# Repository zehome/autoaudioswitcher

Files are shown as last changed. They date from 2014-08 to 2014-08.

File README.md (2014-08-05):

autoaudioswitcher
=================

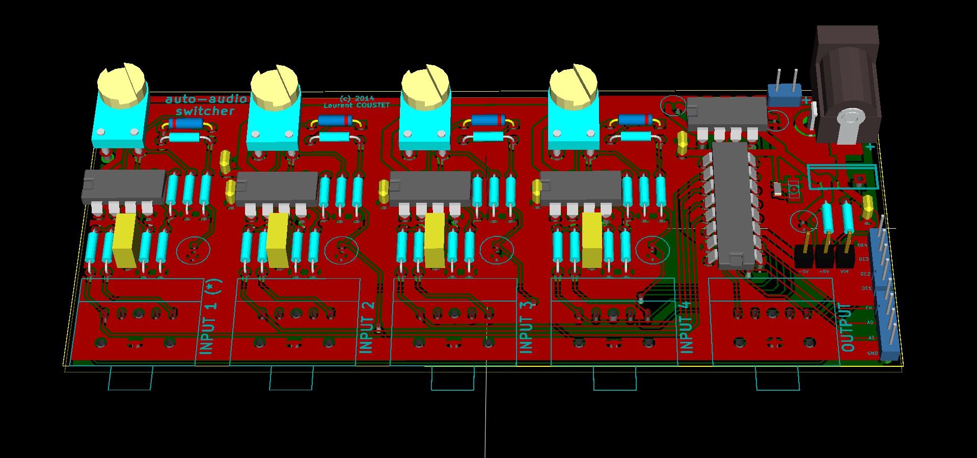
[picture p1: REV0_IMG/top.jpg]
3D_board_rev0


Introduction
------------
With vintage amplifiers, you have limited input switching capabilities. And they are all manual.
This projects aims to solve this problem.

I have an old kenwood KA-4002 (http://www.hifivintage.eu/product.php?id_product=476) which I love.

KA-4002

So, my solution to this problem, automatic audio input switcher.
Basically, the system will detect which audio input has a signal, and switch to it using a solid state MUX.

The project is in early state. Prototype circuit works on a breadbord. First test PCB done and sent to the factory.

Theory of operation
-------------------
Stereo input is muxed using 10k resistors and AC coupled into an amplifier (saturated).
Then, the signal is compared to a reference voltage using a comparator which charges a CAP.
A MCU will then poll the charge of the CAP and trigger the MUX (ADG409) to switch on the output if needed. (Programmed in the MCU)

Status
------
Early design stage.

Breadboard prototype working.

Testing PCB done and sent to the factory. Gerbers available in GERBERS_REV0/.

Tools
-----
KiCAD 20140622 + bzr4027 (r4027)

Hackaday.io entry
-----------------
http://hackaday.io/project/2282-automatic-audio-input-switcher

OSHW: Automatic audio input switcher based on audio activity

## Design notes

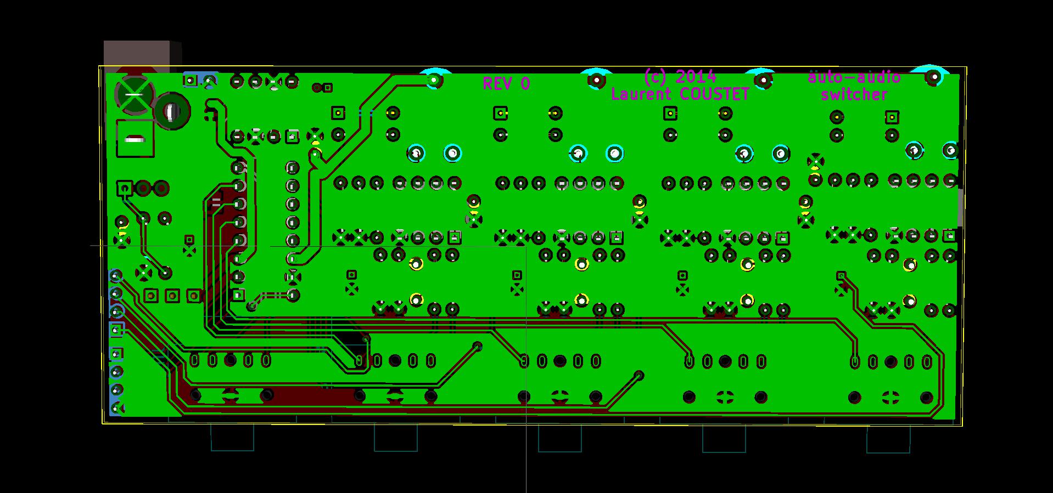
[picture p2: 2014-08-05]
REV0_IMG/bottom.jpg

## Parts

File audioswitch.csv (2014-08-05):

Id | Designator | Package | Quantity | Designation | Supplier and ref
1 | RV1,RV2,RV3,RV4 | RV2X4 | 4 | 100K
2 | R27,R19,R28,R20,R29,R9,R4,R18 | R3 | 8 | 1K
3 | R1,R11,R12,R16,R13,R14,R17,R7,R10,R3,R15,R2 | R3 | 12 | 10K
4 | R22,R31,R23,R32,R8,R30,R5,R21 | R3 | 8 | 100K
5 | R26,R25,R24,R6 | R3 | 4 | 15K
6 | U4,U2,U3,U1 | DIP-8__300 | 4 | LM358
7 | U6 | DIP-8__300 | 1 | TC1044S
8 | U5 | DIP-16__300 | 1 | ADG409
9 | D3,D2,D1,D4 | D3 | 4 | DIODE
10 | C1,C4,C2,C3 | C2 | 4 | 10nF
11 | C10,C7,C9,C8 | C1.5V8V | 4 | 100uF
12 | C6,C5 | C1.5V8V | 2 | 10uF
13 | JACK1 | 3.5MMJACK | 1 | INPUT1
14 | JACK2 | 3.5MMJACK | 1 | INPUT2
15 | JACK3 | 3.5MMJACK | 1 | INPUT3
16 | JACK4 | 3.5MMJACK | 1 | INPUT4
17 | JACKOUT1 | 3.5MMJACK | 1 | OUTPUT1
18 | P2 | PIN_ARRAY_2X1 | 1 | TESTPWR
19 | P1 | JACK_ALIM | 1 | POWER

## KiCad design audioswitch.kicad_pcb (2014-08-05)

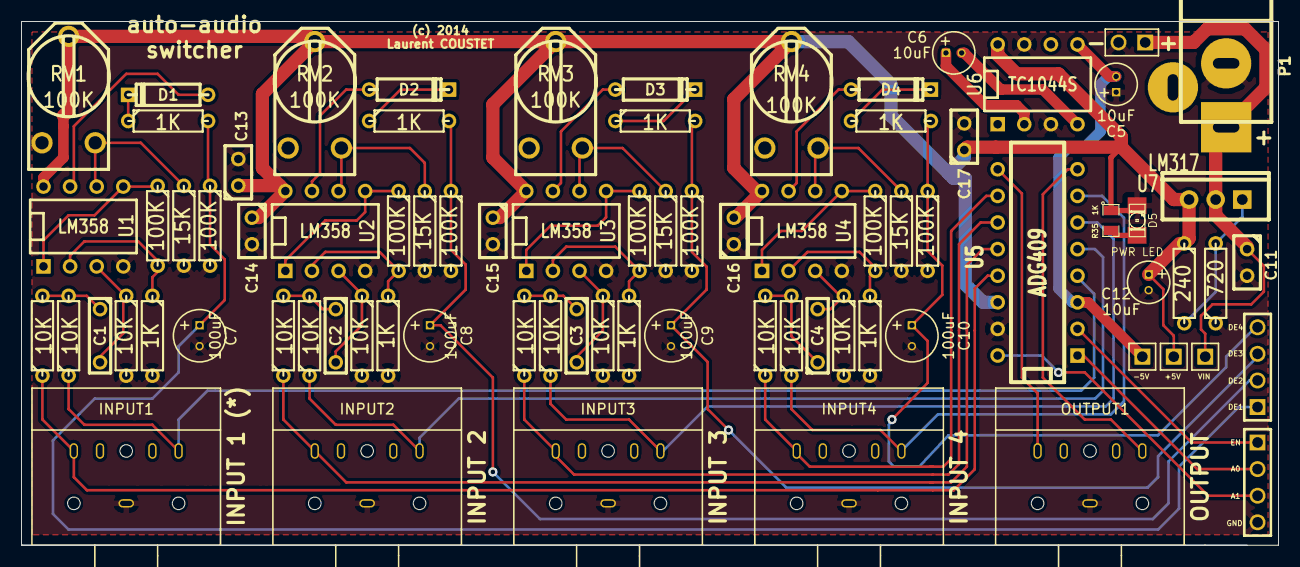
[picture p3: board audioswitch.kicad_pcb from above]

Board: 2 copper layers, 120.0 x 50.0 mm, 80 parts (0 on the bottom side), 53 nets.

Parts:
C1, C2, C3, C4: 10nF; C2
C5, C6, C12: 10uF; C1.5V4
C7, C8, C9, C10: 100uF; C1V5
C11: 0.1uF; C1
C13, C14, C15, C16, C17: 10nF; C1
D1, D2, D3, D4: DIODE; D3
D5: PWR LED; LED-1206
JACK1: INPUT1; 3.5MMJACK
JACK2: INPUT2; 3.5MMJACK
JACK3: INPUT3; 3.5MMJACK
JACK4: INPUT4; 3.5MMJACK
JACKOUT1: OUTPUT1; 3.5MMJACK
P1: POWER; JACK_ALIM
P2: TESTPWR; PIN_ARRAY_2X1
P3: DETECT CONN; PIN_ARRAY_4x1
P5: CTRL CONN; PIN_ARRAY_4x1
R1, R2, R3, R7, R10, R11, R12, R13, R14, R15, R16, R17: 10K; R3
R4, R9, R18, R19, R20, R27, R28, R29: 1K; R3
R5, R8, R21, R22, R23, R30, R31, R32: 100K; R3
R6, R24, R25, R26: 15K; R3
R33: 720; R3
R34: 240; R3
R35: 1K; SM0805
RV1, RV2, RV3, RV4: 100K; RV2X4
TP1: TP -5V; PIN_ARRAY_1
TP2: TP_VIN; PIN_ARRAY_1
TP3: TP_VCC; PIN_ARRAY_1
U1, U2, U3, U4: LM358; DIP-8__300
U5: ADG409; DIP-16__300
U6: TC1044S; DIP-8__300
U7: LM317; TO220_VERT

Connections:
/-5V: C5.2, TP1.1, U5.3, U6.5
/A0: P5.2, U5.1
/A1: P5.3, U5.16
/CH1LEFT: JACK1.5, R1.1, U5.13
/CH1RIGHT: JACK1.4, R2.1, U5.4
/CH2LEFT: JACK2.5, R7.1, U5.12
/CH2RIGHT: JACK2.4, R10.1, U5.5
/CH3LEFT: JACK3.5, R11.1, U5.11
/CH3RIGHT: JACK3.4, R12.1, U5.6
/CH4LEFT: JACK4.5, R13.1, U5.10
/CH4RIGHT: JACK4.4, R14.1, U5.7
/EN: P5.1, U5.2
/VIN: C11.1, P1.1, P2.1, TP2.1, U7.3
AUDIO1_DETECT: C7.1, P3.1, R8.1, R9.2
AUDIO2_DETECT: C8.1, P3.2, R27.2, R30.1
AUDIO3_DETECT: C9.1, P3.3, R28.2, R31.1
AUDIO4_DETECT: C10.1, P3.4, R29.2, R32.1
GND: C5.1, C7.2, C8.2, C9.2, C10.2, C11.2, C12.2, C13.2, C14.2, C15.2, C16.1, C17.2, D5.2, JACK1.1, JACK2.1, JACK3.1, JACK4.1, JACKOUT1.1, P1.2, P2.2, P5.4, R3.2, R4.2, R6.2, R8.2, R15.2, R16.2, R17.2, R18.2, R19.2, R20.2, R24.2, R25.2, R26.2, R30.2, R31.2, R32.2, R33.1, U1.4, U2.4, U3.4, U4.4, U5.15, U6.3, U6.7
unnamed: R6.1, RV1.3, U1.6
unnamed: R24.1, RV2.3, U2.6
unnamed: R25.1, RV3.3, U3.6
unnamed: R26.1, RV4.3, U4.6
unnamed: C4.2, R17.1, U4.3
unnamed: R23.1, U4.1, U4.5
unnamed: C4.1, R13.2, R14.2
unnamed: R20.1, R23.2, U4.2
unnamed: D4.2, R29.1
unnamed: D4.1, U4.7
unnamed: JACKOUT1.5, U5.9
unnamed: R33.2, R34.2, U7.1
unnamed: C6.2, U6.4
unnamed: R5.1, U1.1, U1.5
unnamed: C1.1, R1.2, R2.2
unnamed: JACKOUT1.4, U5.8
unnamed: D1.2, R9.1
unnamed: D1.1, U1.7
unnamed: C1.2, R3.1, U1.3
unnamed: D5.1, R35.2
unnamed: R22.1, U3.1, U3.5
unnamed: C3.1, R11.2, R12.2
unnamed: R18.1, R21.2, U2.2
unnamed: R19.1, R22.2, U3.2
unnamed: D3.2, R28.1
unnamed: D3.1, U3.7
unnamed: C3.2, R16.1, U3.3
unnamed: C2.1, R7.2, R10.2
unnamed: C6.1, U6.2
unnamed: R4.1, R5.2, U1.2
unnamed: D2.2, R27.1
unnamed: D2.1, U2.7
unnamed: C2.2, R15.1, U2.3
unnamed: R21.1, U2.1, U2.5
VCC: C12.1, C13.1, C14.1, C15.1, C16.2, C17.1, R34.1, R35.1, RV1.2, RV2.2, RV3.2, RV4.2, TP3.1, U1.8, U2.8, U3.8, U4.8, U5.14, U6.8, U7.2

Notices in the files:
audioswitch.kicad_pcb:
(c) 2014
